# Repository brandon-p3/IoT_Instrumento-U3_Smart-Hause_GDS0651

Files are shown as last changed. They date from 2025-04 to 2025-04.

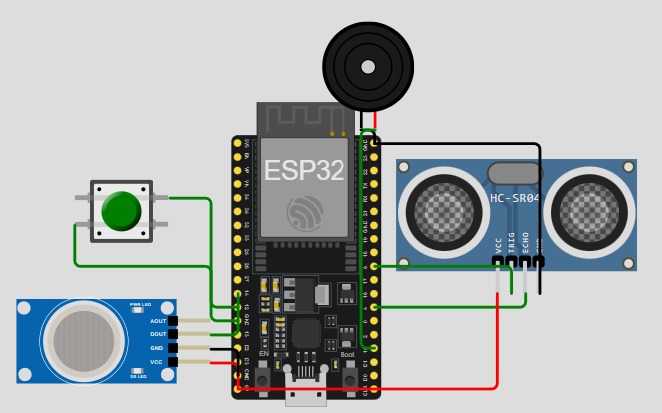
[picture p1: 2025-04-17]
Placa 1 (MQ-02, BUZZER, DISTANCIA)/Diagrama Placa 1.jpg

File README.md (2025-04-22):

# 🏠 SMART-HOME: Sistema Inteligente de Automatización Residencial

## Descripción General

**SMART-HOME** es un sistema de automatización residencial diseñado para cuidar prendas de ropa, optimizar el uso de energía y mejorar la seguridad del hogar mediante sensores y actuadores conectados a través de una red de microcontroladores **ESP32**. Este ecosistema inteligente se coordina mediante **Node-RED** sobre una **máquina virtual en Raspberry Pi**, e incluye visualización gráfica, control manual y almacenamiento de datos en **PostgreSQL**.

El sistema combina sensores de ambiente con controladores mecánicos para realizar acciones automáticas como:
- Proteger la ropa cuando llueve.
- Apagar o encender luces RGB según el nivel de luz natural.
- Detectar humo y actuar en consecuencia.
- Detectar presencia en la puerta principal.
- Controlar actuadores remotamente desde una interfaz gráfica web.

---

## 🎯 Objetivos del Proyecto

- Automatizar procesos domésticos mediante sensores y actuadores.
- Diseñar una solución IoT descentralizada basada en múltiples ESP32.
- Visualizar datos en tiempo real y guardar el histórico en una base de datos PostgreSQL.
- Proporcionar control manual de dispositivos desde una interfaz web construida en Node-RED.
- Crear una maqueta física representativa con componentes impresos en 3D.

---

## ⚙️ Tecnologías Utilizadas

| Tecnología | Uso Principal |
|---|---|
| ESP32 | Microcontroladores para manejar sensores/actuadores |
| Node-RED | Plataforma de control e interfaz web |
| Raspberry Pi | Máquina virtual que aloja Node-RED y PostgreSQL  |
| PostgreSQL | Base de datos relacional para almacenamiento de datos |
| MQTT | Protocolo de mensajería entre nodos ESP32 y Node-RED |
| Impresión 3D | Estructuras físicas y mecanismos personalizados |

---

## 🧠 Arquitectura del Sistema

El sistema está distribuido en **3 placas ESP32**, cada una encargada de distintos sensores y actuadores. La comunicación entre ellas se realiza mediante **MQTT**, utilizando Node-RED como broker e interfaz de control centralizada.

```
        [ESP32-1] ---> Detector de Humo, Buzzer, Ultrasonico
        [ESP32-2] ---> Servo, Motor DC
        [ESP32-3] ---> Motor Paso, Sensor de Lluvia, LDR, LEDs RGB

                      ↕  MQTT
                    [Node-RED]
                        ↕
                    [PostgreSQL]
```

## 🧹 **Tabla de Actuadores**

| **Nombre** | **Tipo** | **Uso** | **Imagen** |
|---|---|---|---|
| **Motor Paso** | Motor (Pasos) | Subir o bajar el techo en caso de lluvia |  |
| **Servo Motor** | Micro ServoMotor | Abrir la ventana si se detecta humo |  |
| **Buzzer Pasivo**  | Actuador Sonoro | Sonar en caso de humo o presencia detectada en puerta |  |
| **Leds RGB** | Iluminación RGB | Encender o apagar según el nivel de luz |  |
| **Motor Micro DC** | Motor DC + Driver | Activar ventilador cuando se detecta humo |  |

---

## 🌧️ **Tabla de Sensores**

| **Nombre** | **Tipo** | **Uso** | **Imagen** |
|---|---|---|---|
| **Sensor Ultrasónico HC-SR04** | Proximidad | Detectar presencia en la entrada principal |  |
| **Detector de Humo MQ-2** | Gas y Humo | Activar alarma, abrir ventana, y prender ventilador |  |
| **Sensor de Lluvia YL-83**  | Humedad superficial | Detectar lluvia para subir el techo |  |
| **Sensor de Luz LDR** | Fotoresistencia | Medir luz natural y controlar luces RGB |  |

---

## 🛠️ Funcionalidad del Sistema

### ☔ Protección contra Lluvia
Cuando el sensor **YL-83** detecta lluvia, se activa el **motor de pasos**, que sube el techo para proteger la ropa tendida.

### ☀️ Control de Iluminación
El sensor **LDR** mide la luz ambiental. Si hay suficiente luz natural, se apagan las luces **RGB**; si hay poca, se encienden automáticamente.

### 🔥 Detección de Gas
El sensor **MQ-2** detecta gases peligrosos, lo que activa:
- El **buzzer** como alarma.
- El **servo motor** para abrir una ventana.
- El **motor DC** para encender un ventilador que ventile el área.

### 🚪 Detección de Presencia
El **sensor ultrasónico HC-SR04** detecta si alguien se encuentra en la puerta principal. En ese caso, se activa el **buzzer** para notificar presencia.

---

## 💻 Interfaz Gráfica

La interfaz fue desarrollada en **Node-RED** y permite:
- Controlar manualmente el techo, ventilador y ventana.
- Visualizar gráficas en tiempo real de los sensores.
- Encender/apagar los actuadores desde cualquier navegador.
- Visualizar graficas y metricas sobre el estado de las ultimas 10 detecciones por parte del MQ-02
- Visualizar graficas y metricas sobre la duracion (Horas) de las lluvia en las ultimas 10 detecciones de lluvia

**Ejemplo de interfaz:**


---

## 🏠 Maqueta Física

La casa fue creada con materiales comunes de maqueta, pero incorpora piezas funcionales impresas en 3D como:
- El mecanismo del techo móvil.
- Soportes para sensores y actuadores.
- Estructuras para ventanas funcionales.

**📸 Imágenes de la maqueta del proyecto**
<div style="display: flex; flex-wrap: wrap; gap: 20px; justify-content: center; margin-top: 20px;"> Imagen 1 Imagen 2 Imagen 3 Imagen 4 Imagen 4 </div>

---
## 🏠 Diagramas de las placas

**Placa 1 (MQ-02, BUZZER, DISTANCIA)**
<br>
Link: https://wokwi.com/projects/427323546919923713 

<br>
**Placa 2 (SERVO, MOTOR DC)**
<br>
Link: https://wokwi.com/projects/427323546919923713


<br>

**Placa 3 (LLUVIA, LDR, RGB, MOTOR-PASOS)**

<br>
Link: https://app.cirkitdesigner.com/project/b07a5b19-9e06-4433-bb01-3e5187981fbb 

---

## 🧪 Base de Datos y Almacenamiento

El sistema guarda todos los datos generados por los sensores en una base de datos **PostgreSQL**, permitiendo:
- Consultas históricas de temperaturas, humo, lluvia, presencia, etc.
- Análisis estadístico posterior.
- Exportación de datos para informes o visualización externa.

**Funcionamiento envio correo**





---

## Videos explicando el funcionamiento de cada placa

Link a videos

https://drive.google.com/drive/folders/1Mwg-OasbqF_vHa8ZhzucIkqC5u0zefmu?usp=drive_link

## Videos explicando el funcionamiento general de toda la casa

Link a videos

https://drive.google.com/drive/folders/12ORMXZAib9PHsuYNOvswGEr8jB9Gjxr0?usp=sharing

## Evidencia (Videos) de los clientes que aprueban el proyecto

Link a videos

https://drive.google.com/drive/folders/1yig3J2GGEPOLDp7m1ZyxWFej3fN-4ZA3?usp=sharing

## Evidencia (Documento firmado) de los clientes que aprueban el proyecto

Link al documento

https://drive.google.com/file/d/1-QUlkMJvc9JZO_qd18DEQOQgmpPzMd11/view?usp=sharing

---

## Ejecicios de Clase

Link a videos

https://drive.google.com/drive/folders/1GOXApjWNVipbJKVLVaaz4QoqaaGXq0BR?usp=sharing

## Coevaluación

https://docs.google.com/document/d/1jDS9AxsSn1z5lsY4fK3YzhkUiO5Kk1glECyVzDjCRfc/edit?usp=sharing

---

## ✍️ Autores

- **Nombre del equipo**: SmartHome GDS0651
- **Integrantes**:
  - Mendoza Amaro Brandon Gustavo - brandon-p3
  - Morales Lezama Mirza Natzielly  - Mirza Morales
  - Ramirez Ramirez Lizett 

---

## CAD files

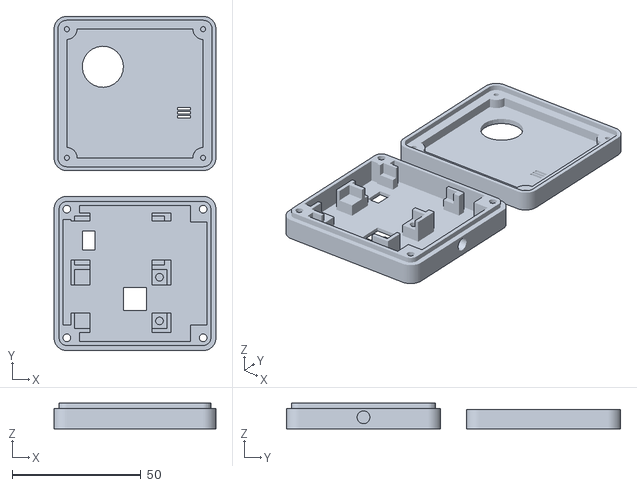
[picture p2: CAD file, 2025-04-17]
Modelo-3D/MQ-02 Y buzzer_Modelo_3D.stl
63.0 x 130.0 x 10.00

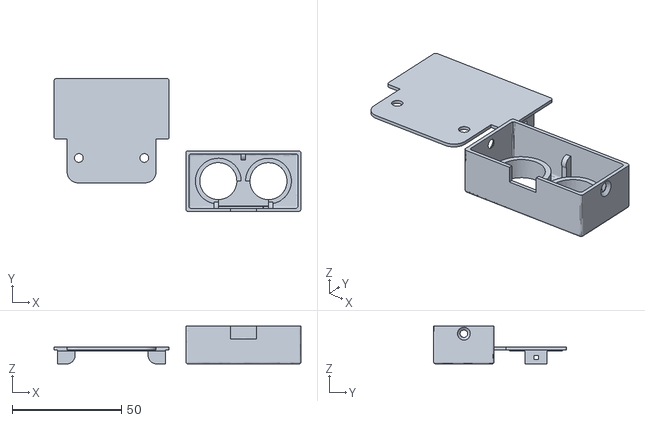
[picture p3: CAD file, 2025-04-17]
Modelo-3D/Sensor Distancia_Modelo_3D.stl
113.2 x 60.9 x 17.4

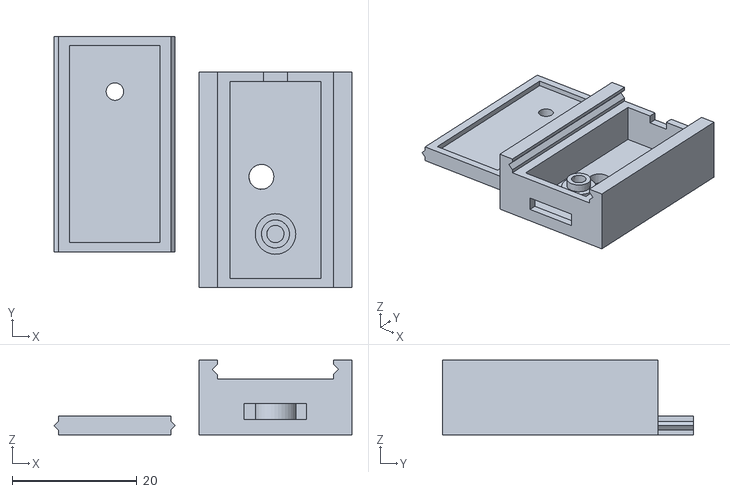
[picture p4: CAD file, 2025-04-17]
Modelo-3D/Sensor LDR_Modelo_3D.stl
47.7 x 40.2 x 12.0

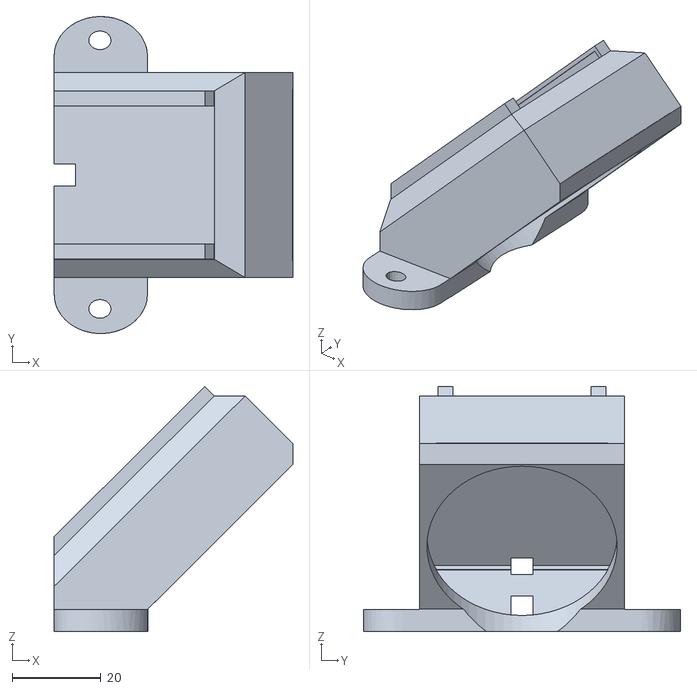
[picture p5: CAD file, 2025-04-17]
Modelo-3D/Sensor-Lluvia_Modelo_3D.stl
53.9 x 71.5 x 55.3

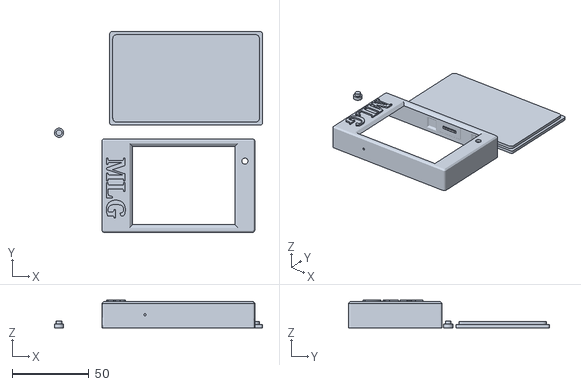
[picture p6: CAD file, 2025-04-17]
Modelo-3D/Carcasa_Pantalla_ESP32.stl
135.7 x 131.0 x 18.0

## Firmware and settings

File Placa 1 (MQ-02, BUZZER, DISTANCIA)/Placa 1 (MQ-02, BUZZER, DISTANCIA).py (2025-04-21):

from machine import Pin, PWM, ADC
from network import WLAN, STA_IF
from time import sleep, ticks_us, ticks_diff
from urequests import post
import network
import time
from umqtt.simple import MQTTClient
import ujson 

# -------------------- Configuración WiFi y MQTT --------------------
SSID = "Megacable_RdLp84U"
PASSWORD = "99uh6AmygyWEqfKzz2"
MQTT_BROKER = "192.168.0.35"
MQTT_TOPIC = "smartHause/sensor/humo"
MQTT_TOPIC2 = "smartHause/sensor/ultrasonico"
MQTT_TOPIC3 = "smartHause/sensor/humo/enviar"

WEBAPP_URL = "https://script.google.com/macros/s/AKfycbxquHQl_BTEvyTmLvFuprc6-cgBMk5CS_9Bi1On_ugHJRyU1PBxXZhFdadoQSsPd9cF/exec"

# --- Buzzer ---
buzzer = PWM(Pin(15), freq=1000)
buzzer.duty(0)

# --- Sensor Ultrasonico HC-SR04 ---
trig = Pin(5, Pin.OUT)
echo = Pin(4, Pin.IN)

# --- Sensor de gas MQ-2 (Analógico) ---
mq2 = ADC(Pin(34))
mq2.atten(ADC.ATTN_11DB)
mq2.width(ADC.WIDTH_10BIT)

# --- Botón de reset ---
boton_reset = Pin(12, Pin.IN, Pin.PULL_UP)

# -------------------- Conexión WiFi --------------------
wifi = network.WLAN(network.STA_IF)
wifi.active(True)
wifi.connect(SSID, PASSWORD)

while not wifi.isconnected():
    print("Conectando a WiFi...")
    time.sleep(1)

print("✅ Conectado a WiFi!")

# -------------------- Conexión MQTT --------------------
try:
    client = MQTTClient("ESP32", MQTT_BROKER)
    client.connect()
    print("✅ Conectado a MQTT!")
except OSError as e:
    print("❌ Error al conectar a MQTT:", e)
    raise

# -------------------- Funciones --------------------
def enviar_alerta_gas(nivel):
    try:
        data = {
            "sensor": "MQ-2",
            "nivel": nivel
        }
        response = post(WEBAPP_URL, json=data)
        print("📩 Alerta enviada: ", response.text)
        response.close()
    except Exception as e:
        print("❌ Error al enviar alerta:", e)

def medir_distancia():
    trig.value(0)
    sleep(0.002)
    trig.value(1)
    sleep(0.01)
    trig.value(0)

    timeout = 10000
    while echo.value() == 0 and timeout > 0:
        timeout -= 1
    if timeout <= 0:
        return 999

    inicio = ticks_us()

    timeout = 10000
    while echo.value() == 1 and timeout > 0:
        timeout -= 1
    if timeout <= 0:
        return 999

    fin = ticks_us()
    duracion = ticks_diff(fin, inicio)
    distancia = duracion / 58.0
    return distancia

def sonar_timbre():
    tonos = [880, 988, 1047]
    for _ in range(2):
        for tono in tonos:
            buzzer.freq(tono)
            buzzer.duty(512)
            sleep(0.15)
            buzzer.duty(0)
            sleep(0.05)
    sleep(2)

def sonar_alarma():
    buzzer.freq(2000)
    buzzer.duty(512)

def detener_alarma():
    buzzer.duty(0)

# -------------------- Variables de control --------------------
umbral_gas = 1000
alerta_enviada = False
alarma_activa = False
alarma_desactivada_por_usuario = False

# -------------------- Loop principal --------------------
while True:
    # --- Sensor ultrasonico ---
    distancia = medir_distancia()
    if distancia < 999:
        if distancia < 20:
            print("🚪 Hay alguien en la puerta")
            mensaje = ujson.dumps({
                "id_sensor": 4,  
                "mensaje": "Hay alguien en la puerta",
                "valor": distancia
            })
            client.publish(MQTT_TOPIC2, mensaje.encode())
            sonar_timbre()
    else:
        print("⚠ Error al medir distancia")

    # --- Sensor de gas ---
    nivel_gas = mq2.read()

    if nivel_gas > umbral_gas and not alarma_desactivada_por_usuario:
        print("🚨 ¡Gas detectado!")
        if not alerta_enviada:
            enviar_alerta_gas(nivel_gas)
            alerta_enviada = True
            mensaje = ujson.dumps({
                "id_sensor": 4,  
                "mensaje": "Hay una alta concentración de humo dentro de la casa, !!PELIGRO¡¡",
                "valor": nivel_gas
            })
            client.publish(MQTT_TOPIC, mensaje.encode())
            client.publish(MQTT_TOPIC3, str(nivel_gas))

        alarma_activa = True
        inicio = time.time()

        # 🔁 Mantenerse en modo alerta durante 60 segundos
        while time.time() - inicio < 60:
            sonar_alarma()
            if boton_reset.value() == 0:
                print("🔕 Alarma desactivada por el usuario")
                alarma_activa = False
                alarma_desactivada_por_usuario = True
                detener_alarma()
                break
            sleep(0.2)

    else:
        if nivel_gas <= umbral_gas:
            alarma_desactivada_por_usuario = False
            alerta_enviada = False
            alarma_activa = False
            detener_alarma()
            client.publish(MQTT_TOPIC3, str(0))
        else:
            print("✅ Nivel de gas normal")
            sleep(5)

    sleep(0.2)

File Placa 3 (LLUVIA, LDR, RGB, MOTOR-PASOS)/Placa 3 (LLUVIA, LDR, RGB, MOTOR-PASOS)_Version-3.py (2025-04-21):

from machine import Pin, PWM
from time import sleep, ticks_ms
from network import WLAN, STA_IF
from urequests import post
import network
import time
from umqtt.simple import MQTTClient
import ujson  # Para enviar mensajes en formato JSON

# -------------------- Configuración WiFi y MQTT --------------------
SSID = "Megacable_RdLp84U"
PASSWORD = "99uh6AmygyWEqfKzz2"
MQTT_BROKER = "192.168.0.35"

MQTT_TOPIC_LUZ = "smartHause/sensor/foto"
MQTT_TOPIC_LLUVIA = "smartHause/sensor/lluvia"
MQTT_TOPIC_CONTROL = "smartHause/sensor/recibir"  # ← desde aquí llega el control manual
WEBAPP_URL = "https://script.google.com/macros/s/AKfycbwUAJTQPAj-ZQZzAC70R7lXyaS_WqebFC5XXQ86ZCI-78HFhON8aqx9ZC74AWeuM8Tl/exec"

# -------------------- Pines --------------------
IN1 = Pin(25, Pin.OUT)
IN2 = Pin(26, Pin.OUT)
IN3 = Pin(33, Pin.OUT)
IN4 = Pin(32, Pin.OUT)
pins = [IN1, IN2, IN3, IN4]

sensor_agua = Pin(14, Pin.IN)
sensor_luz = Pin(16, Pin.IN)

led_rojo = PWM(Pin(5), freq=1000)
led_verde = PWM(Pin(4), freq=1000)
led_azul = PWM(Pin(2), freq=1000)

# -------------------- Motor: Secuencias --------------------
sequence_right = [  # Cerrar techo
    [0, 0, 0, 1],
    [0, 0, 1, 0],
    [0, 1, 0, 0],
    [1, 0, 0, 0]
]
sequence_left = sequence_right[::-1]  # Abrir techo

# -------------------- Funciones: Motor y LED --------------------
def step_motor_time(sequence, delay, duration_sec):
    start = ticks_ms()
    while ticks_ms() - start < duration_sec * 1000:
        for step in sequence:
            for i in range(4):
                pins[i].value(step[i])
            sleep(delay)
    apagar_motor()

def apagar_motor():
    for pin in pins:
        pin.value(0)

def abrir_techo():
    print("🔄 Abriendo techo...")
    step_motor_time(sequence_left, delay=0.005, duration_sec=2)

def cerrar_techo():
    print("🔄 Cerrando techo...")
    step_motor_time(sequence_right, delay=0.005, duration_sec=3)

def set_color(r, g, b):
    led_rojo.duty(1023 - r)
    led_verde.duty(1023 - g)
    led_azul.duty(1023 - b)

def encender_rgb_calido():
    set_color(r=1023, g=400, b=0)

def apagar_rgb():
    set_color(0, 0, 0)

# -------------------- Conexión WiFi --------------------
wifi = network.WLAN(network.STA_IF)
wifi.active(True)
wifi.connect(SSID, PASSWORD)

while not wifi.isconnected():
    print("Conectando a WiFi...")
    time.sleep(1)
print("✅ Conectado a WiFi!")

# -------------------- MQTT --------------------
def llegada_mensaje(topic, msg):
    mensaje = msg.decode()
    print("📥 Mensaje recibido en", topic.decode(), ":", mensaje)

    if topic.decode() == MQTT_TOPIC_CONTROL:
        if mensaje == "0":
            abrir_techo()
        elif mensaje == "1":
            cerrar_techo()
        else:
            print("⚠ Comando desconocido")
            
def send_to_sheets(temp, hum):
    data = {
        "msj": temp,
        "valor": hum
    }
    try:
        response = post(WEBAPP_URL, json = data)
        print("Respuesta Guardada: ", response.text)
        response.close()

    except Exception as e:
        print("Error al enviar los datos a la hoja de calculo", e)


client = MQTTClient("ESP32_SISTEMA", MQTT_BROKER)
client.set_callback(llegada_mensaje)
client.connect()
client.subscribe(MQTT_TOPIC_CONTROL.encode())
print("✅ Suscrito a:", MQTT_TOPIC_CONTROL)

# -------------------- Estado inicial --------------------
print("🛠️ Sistema iniciado. Abriendo techo por seguridad...")
abrir_techo()
estado_anterior_agua = 0
estado_anterior_luz = sensor_luz.value()
lluvia_en_curso = False
tiempo_inicio_lluvia = 0

# -------------------- Bucle principal --------------------
while True:
    # --- Sensor de agua (modo automático) ---
    estado_actual_agua = sensor_agua.value()
    print("Hola")
    if estado_actual_agua != estado_anterior_agua:
        if estado_actual_agua == 1:
            print("💧 Agua detectada. Cerrando techo.")
            cerrar_techo()
            mensaje = ujson.dumps({
                "id_sensor": 4,  
                "mensaje": "Agua detectada. Techo cerrado.",
                "valor": 0
            })
            send_to_sheets("Esta lloviendo afuera, el techo a sido bajado para protegerlo", 0)
            client.publish(MQTT_TOPIC_LLUVIA, mensaje.encode())
            lluvia_en_curso = True
            tiempo_inicio_lluvia = ticks_ms()
        else:
            print("✅ No hay agua. Abriendo techo.")
            abrir_techo()
            if lluvia_en_curso:
                duracion_ms = ticks_ms() - tiempo_inicio_lluvia
                duracion_horas = round(duracion_ms / (1000 * 60 * 60))
                if duracion_horas == 0:
                    duracion_horas = 1
                print(f"⏱️ Duración de la lluvia: {duracion_horas} horas")
                mensaje = ujson.dumps({
                    "id_sensor": 4,
                    "mensaje": "Lluvia finalizada. Duración en horas.",
                    "valor": duracion_horas
                })
                send_to_sheets("Ha dejado de llover, se bajara el techo", duracion_horas)
                client.publish(MQTT_TOPIC_LLUVIA, mensaje.encode())
                lluvia_en_curso = False
        estado_anterior_agua = estado_actual_agua

    # --- Sensor de luz (iluminación nocturna) ---
    estado_actual_luz = sensor_luz.value()
    if estado_actual_luz != estado_anterior_luz:
        if estado_actual_luz == 1:
            print("🌙 Noche detectada. Encendiendo entrada.")
            encender_rgb_calido()
            mensaje = ujson.dumps({
                "id_sensor": 4,  
                "mensaje": "Noche detectada. Luz encendida.",
                "valor": 1
            })
            client.publish(MQTT_TOPIC_LUZ, mensaje.encode())
        else:
            print("☀️ Día detectado. Apagando luces.")
            apagar_rgb()
            mensaje = ujson.dumps({
                "id_sensor": 4,  
                "mensaje": "Día detectado. Luz apagada.",
                "valor": 0
            })
            client.publish(MQTT_TOPIC_LUZ, mensaje.encode())
        estado_anterior_luz = estado_actual_luz
    client.check_msg()  # Recibir mensajes manuales

    sleep(1)

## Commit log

2025-04-17 Primer git
    [Carcasa_Pantalla_ESP32.stl, MQ-02 Y buzzer_Modelo_3D.stl, Sensor Distancia_Modelo_3D.stl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]
2025-04-20 Envio de correos
